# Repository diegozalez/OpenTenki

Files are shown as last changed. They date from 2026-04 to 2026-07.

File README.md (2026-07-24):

# OpenTenki 🚧 Construction in progress 🚧

<table>
  <tr>
    <td valign="middle" width="50%">
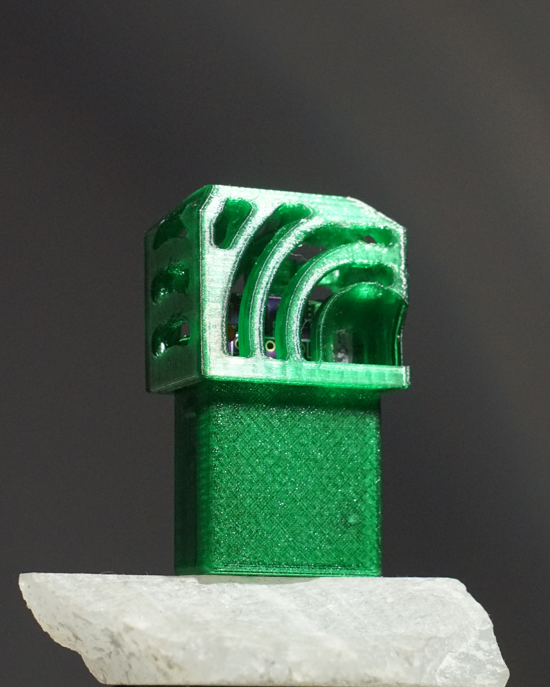
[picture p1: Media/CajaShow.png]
OpenTenki weather station
      
    </td>
    <td valign="middle">
      OpenTenki is an open-source, affordable, and precise indoor weather station
      hardware platform built around an ESP32-S3 mini and multiple environmental
      sensors. It is designed for hobbyists and is compatible with ESPHome and
      Tasmota firmware, enabling easy integration with home automation systems
      via MQTT or Matter.
    </td>
  </tr>
</table>

## Features

<table>
  <tr>
    <td valign="middle">
      <ul>
        <li>Accurate environmental sensing with:
          <ul>
            <li>VEML7700 (ambient light, infrared and full-spectrum light)</li>
            <li>BME688 (temperature, humidity, pressure, air quality)</li>
            <li>HDC3022 (high-precision temperature and humidity)</li>
            <li>WS2812C (NeoPixel) status LED</li>
            <li>User button for control and feedback</li>
          </ul>
        </li>
        <li>Based on the ESP32-S3 mini for robust Wi-Fi and Bluetooth connectivity</li>
        <li>Fully open-source hardware and software</li>
        <li>Designed for easy customization and extension</li>
        <li>Supports MQTT and Matter protocols for data transmission</li>
      </ul>
    </td>
    <td valign="middle" width="50%">
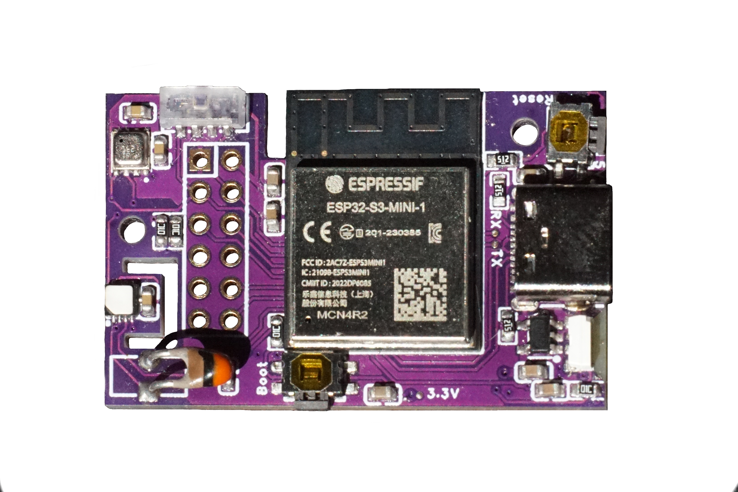
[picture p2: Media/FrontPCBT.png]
OpenTenki PCB render
      
    </td>
  </tr>
</table>

---

## Repository Structure

- [`PCB/`](PCB) — Schematic, Gerber files, BOM, EasyEDA project and PCB renders
- [`Code/`](Code) — Firmware integrations (ESPHome, Tasmota, more coming)
- [`Case3D/`](Case3D) — 3D-printable case files
- [`Media/`](Media) — Photos and renders of the board and case

---

## Getting Started

### Hardware

<table>
  <tr>
    <td valign="middle" width="50%">
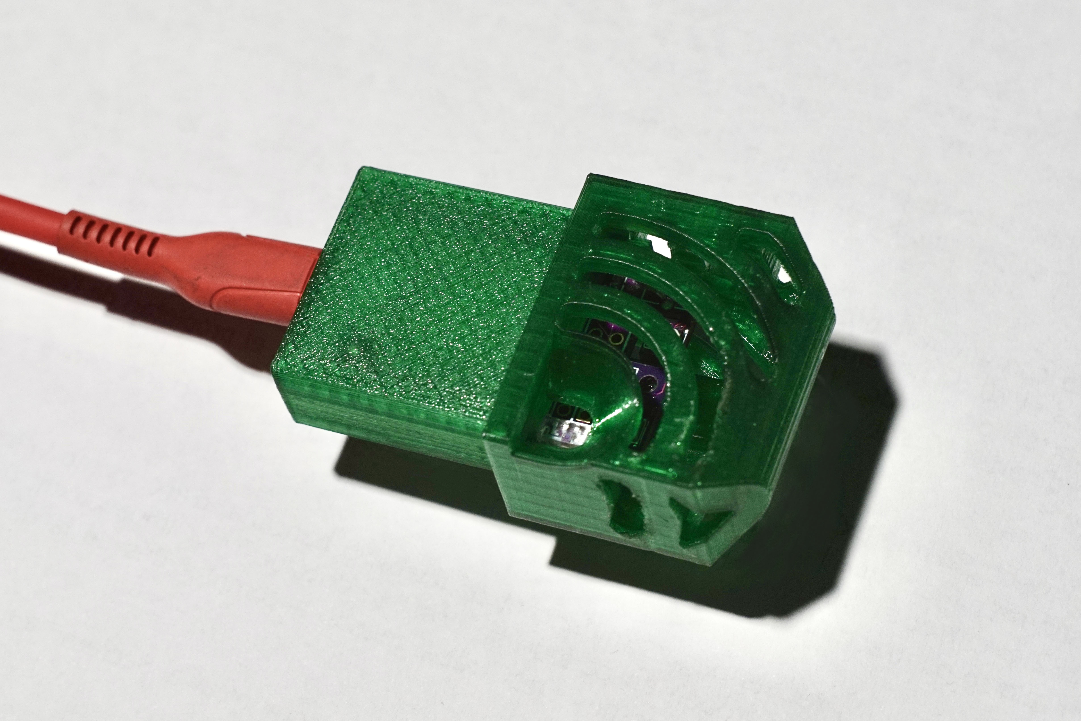
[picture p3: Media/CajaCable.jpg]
OpenTenki assembled, powered over USB-C
      
    </td>
    <td valign="middle">
      <ul>
        <li>Order the PCB with the <a href="PCB/Gerber_PCB2_2026-04-26">Gerber files</a>
          and the <a href="PCB/BOM_OpenTenki_PCB2_2026-07-24.xlsx">BOM</a> — see the
          <a href="PCB">PCB folder</a> for the schematic, the interactive BOM and the
          full EasyEDA project.</li>
        <li>3D-print the <a href="Case3D">case</a>: three printed parts and one screw.</li>
      </ul>
    </td>
  </tr>
</table>

### Firmware

- Compatible with [ESPHome](https://esphome.io/) and
  [Tasmota](https://tasmota.github.io/) out of the box.
- Custom firmware (Arduino, etc.) is in development — contributions welcome!

### Usage

1. Flash ESPHome or Tasmota firmware configured for OpenTenki sensors
   (see [`Code/EspHome/`](Code/EspHome) for a ready-to-use YAML).
2. Connect the board to power and Wi-Fi.
3. Integrate the sensor data with your home automation platform via MQTT or Matter.

---

## Contributing

Contributions, bug reports and feature requests are more than welcome! Please
open an issue or a pull request on GitHub.

---

## License

OpenTenki is licensed under the Apache License 2.0. See [LICENSE](LICENSE) for
details.

---

## Contact

For questions or discussions, open an issue or contact diegozalezz@gmail.com.

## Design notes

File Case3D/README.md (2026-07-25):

# OpenTenki 3D-Printed Case

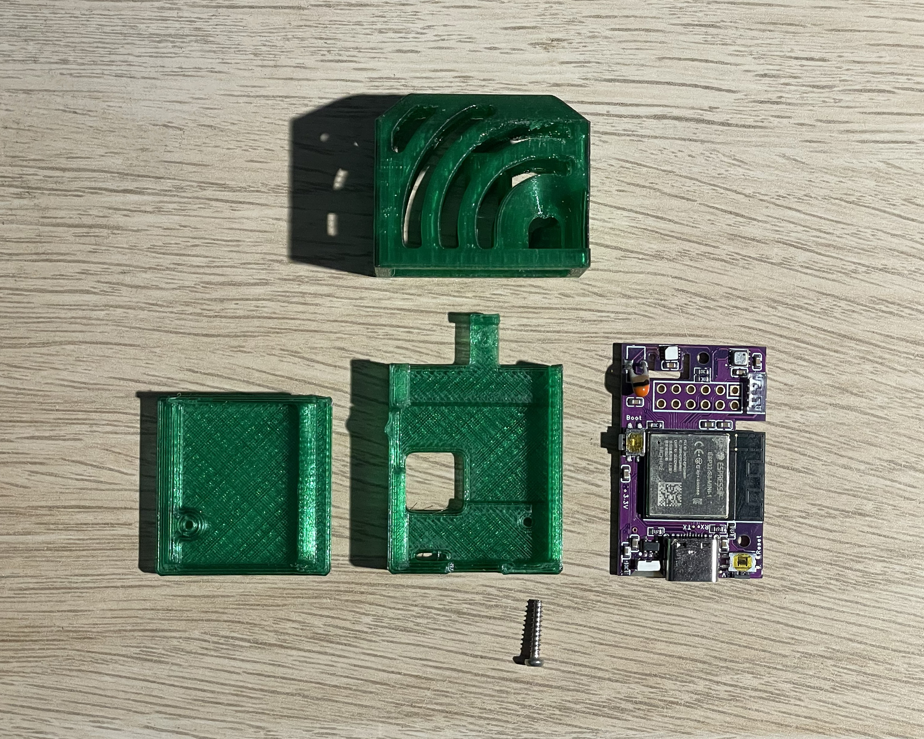
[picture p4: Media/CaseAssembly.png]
The three printed parts, the PCB and the M2×10 screw


The case consists of **three 3D-printed parts** that fit around the PCB and are
secured with a single **M2×10 plastic screw**.

You can also find this model on
[Printables](https://www.printables.com/model/1790374-opentenki-case).

## What you need

- The three `.stl` files in this folder
- An assembled OpenTenki PCB
- 1 × M2×10 plastic screw

## Print & assemble

1. Print the three STL files — standard PLA or PETG settings work fine.
2. Fit the PCB inside the case parts as shown in the picture above.
3. Close the case with the M2×10 screw. Done!

## Modifying the case

The case is designed in [Onshape](https://www.onshape.com/) and the full
assembly is included as a STEP file
([`3D_PCB2_2026-04-23.step`](3D_PCB2_2026-04-23.step)), so you are free to
modify or remix it as you wish.

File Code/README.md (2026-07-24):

# OpenTenki Firmware

Here you can find all the firmware integrations for OpenTenki. In this project
it is very important to be as open and as compatible as possible, so if there
is a platform you would like covered (or that you can adapt OpenTenki to), let
me know — it will only make the project better.

## ESPHome / Home Assistant

The recommended path. The full implementation lives in
[`EspHome/opentenki-v2.yaml`](EspHome/opentenki-v2.yaml) and works great: every
sensor is exposed, the status LED is fully integrated, and pressing the
on-board button confirms connectivity to Home Assistant. The board can also
calculate indoor air quality (IAQ) through the BME688's BSEC2 stack.

## Tasmota

A working [basic template](Tasmota) is available: the BME688, HDC3022, user
button and LED work out of the box (the VEML7700 needs a custom-compiled
binary). Tasmota's ESP32-S3 support is still maturing, so expect some rough
edges — feedback is welcome.

## Arduino — Coming Soon

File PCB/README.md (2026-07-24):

# OpenTenki PCB

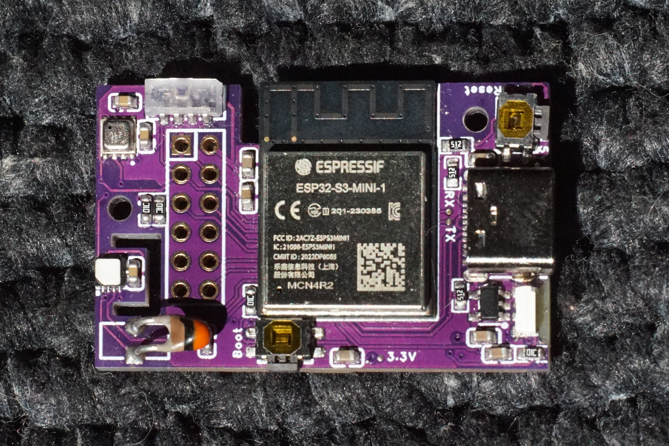
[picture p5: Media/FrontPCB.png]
PCB picture

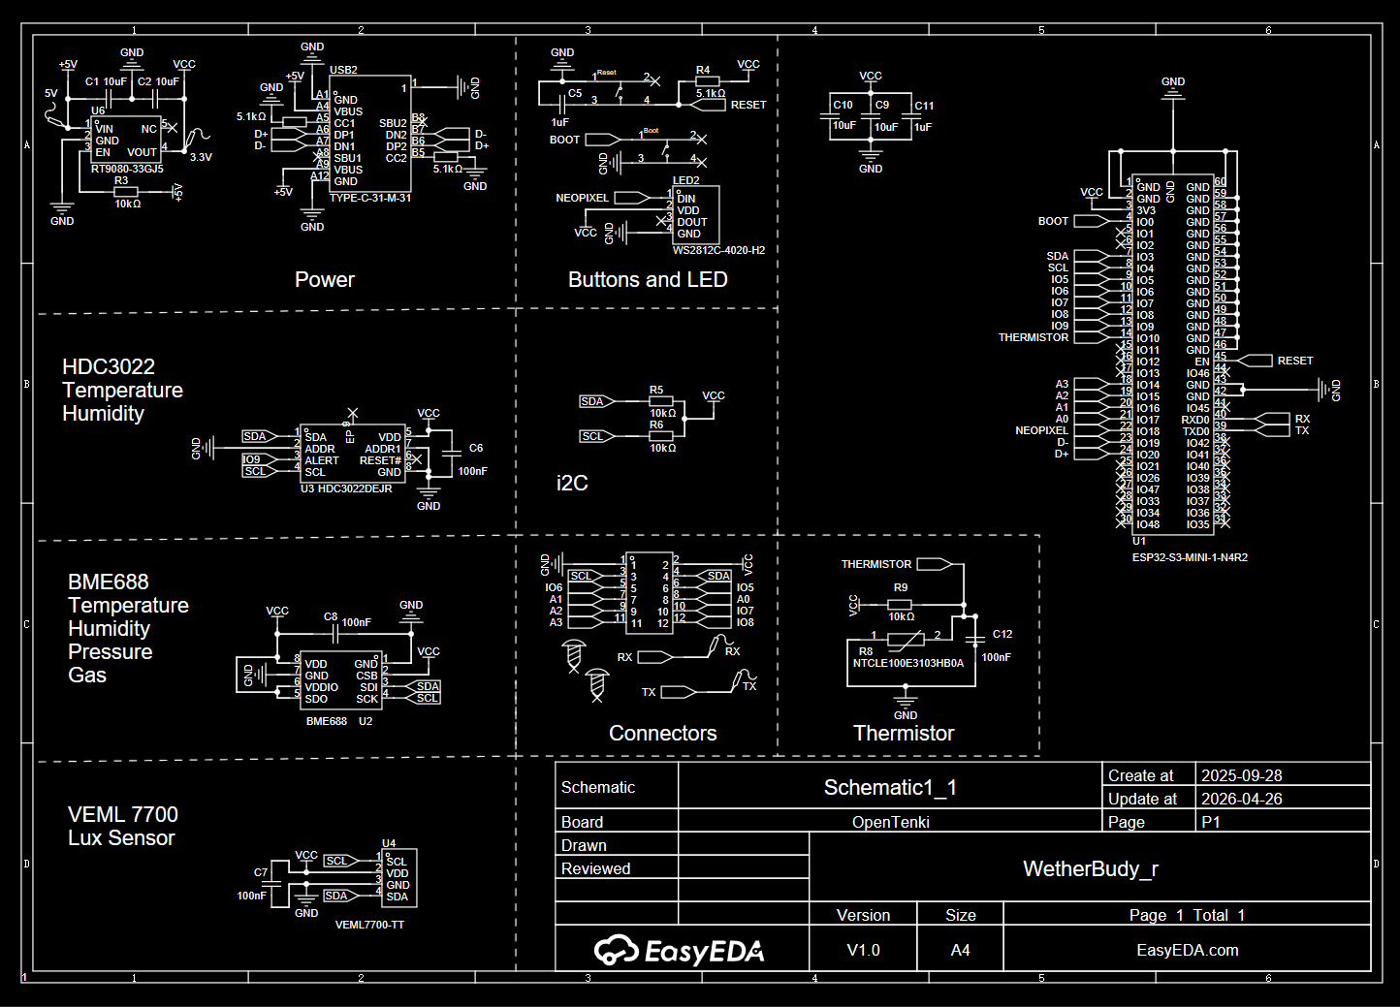
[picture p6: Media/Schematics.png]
Schematic


## Build your own

Everything you need to order and assemble the board:

- [**BOM (Excel)**](BOM_OpenTenki_PCB2_2026-07-24.xlsx) — full part list with LCSC part numbers.
- [**Interactive BOM**](InteractiveBOM_PCB2_2026-4-25.html) — download and open in your browser to locate every component on the board. Very handy for hand soldering.
- [**Gerber files**](Gerber_PCB2_2026-04-26) — ready to send to JLCPCB or any other PCB fab.
- [**Schematic**](SchematicV2.pdf) and [**PCB preview**](PCB_OpenTenki.pdf) as PDF.
- [**EasyEDA project**](OpenTenkiEasyEda.eprj) — the full editable design.

## Components

### Microcontroller

#### ESP32-S3-mini N4R2

This module is great because, in a small form factor, it provides Wi-Fi,
Bluetooth, USB OTG, 4 MB of Quad Flash and 2 MB of Quad PSRAM. It is also
compatible with ESPHome, Tasmota, Arduino, CircuitPython and MicroPython.

### Sensors

All sensors are connected over I²C, with **SDA on GPIO3** and **SCL on GPIO4**.

#### Bosch BME688

Used to monitor air quality, as well as pressure, temperature and humidity.

#### VEML7700

Measures ambient light, infrared and full-spectrum light. A cheap and reliable
option.

#### HDC3022

This last sensor measures temperature and humidity much more precisely than the
BME688 and is significantly cheaper, so if you don't need air quality or
atmospheric pressure it's a great choice. It's also useful any time you want
more precise readings.

## Extras

### WS2812C on GPIO18

Usually known as a NeoPixel, this small status LED can be used for anything,
but its primary use is in ESPHome — the included configuration uses it to show
boot status and to confirm Home Assistant connectivity when the user button is
pressed.

### Button on GPIO0

Doubles as the bootloader button (to flash the board) and as a user button to
check status or to trigger an action on your server.

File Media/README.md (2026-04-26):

# Media for OpenTenki

This folder contains photos and renders of the OpenTenki board and case, used
throughout the rest of the documentation.

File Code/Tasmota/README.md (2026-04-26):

# OpenTenki on Tasmota

With the basic template below you get the BME688, the HDC3022, the user button
and the LED working. The VEML7700 is **not** included by default — to enable it
you need to use a custom-compiled Tasmota binary.

## Basic Template

```json
{"NAME":"OpenTenki","GPIO":[32,1,1,640,608,1,1,1,1,1,1,1,1,1,1,1,1,1,1,1,1,1,1376,0,0,0,0,1,1,1,1,1,1,1,1,1,1,1],"FLAG":0,"BASE":1}
```

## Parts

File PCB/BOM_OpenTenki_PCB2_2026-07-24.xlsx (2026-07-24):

Manufacturer Part | Manufacturer | Value | Supplier | Name | Supplier Part
BME688,CC0603KRX7R9BB104,CL10A105KB8NNNC,CL10A106KP8NNNC,ESP32-S3-MINI-1-N4R2,HDC3022DEJR,NTCLE100E3103HB0A,RC0603FR-075K1L,RC0603FR-0710KL,RT9080-33GJ5,TSD4A 250gf-DZ,TYPE-C-31-M-31,VEML7700-TT,WS2812C-4020-H2,ZX-PZ2.54-2-6PZZ | Bosch(博世),ESPRESSIF(乐鑫),Megastar(兆星),SAMSUNG(三星),SHOU HAN(首韩),TECH PUBLIC(台舟),TI(德州仪器),VISHAY(威世),worldsemi,YAGEO(国巨),韩国韩荣 | 1uF,5.1kΩ,10kΩ,10uF,100nF | LCSC | 1uF,5.1kΩ,10kΩ,10uF,100nF,BME688,ESP32-S3-MINI-1-N4R2,HDC3022DEJR,NTCLE100E3103HB0A,RT9080-33GJ5,TSD4A 250gf-DZ,TYPE-C-31-M-31,VEML7700-TT,WS2812C-4020-H2,ZX-PZ2.54-2-6PZZ | C14663,C15849,C19702,C98220,C105580,C431531,C1850416,C2760486,C3013941,C3153241,C3664478,C7501277,C17434731,C20617299,C42417604

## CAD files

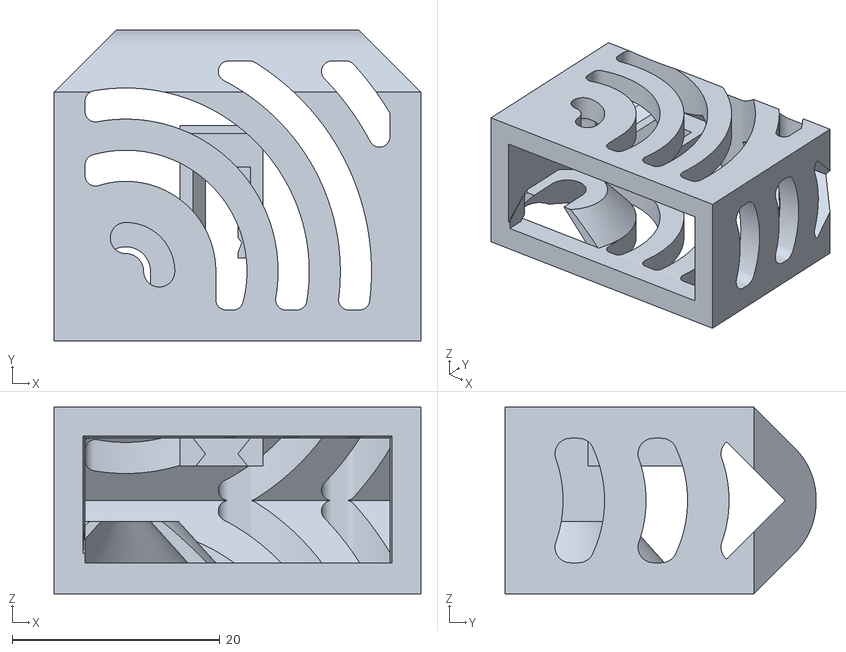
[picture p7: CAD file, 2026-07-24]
Case3D/3D_PCB2_2026-04-23 - Board~3TSI - Part 4.stl
35.4 x 30.0 x 18.0

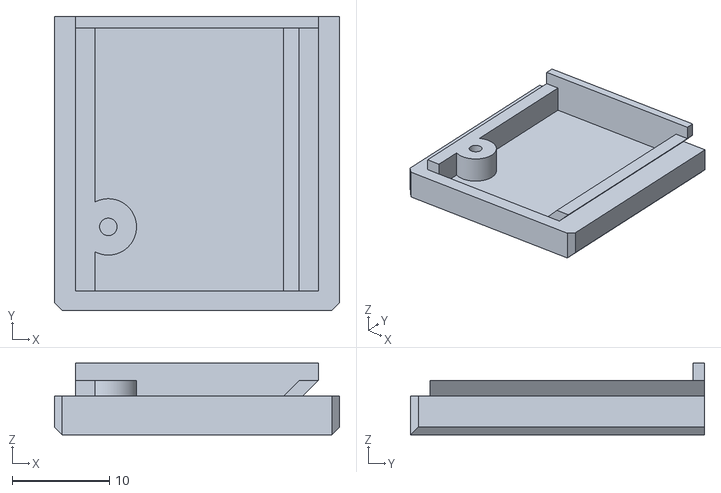
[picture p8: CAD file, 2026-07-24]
Case3D/3D_PCB2_2026-04-23 - Board~3TSI - Part 2.stl
29.4 x 30.3 x 7.40

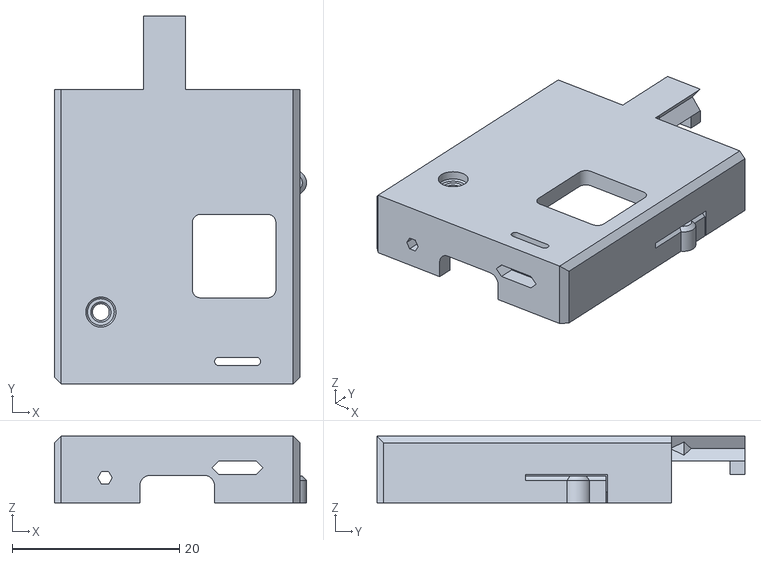
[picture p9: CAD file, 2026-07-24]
Case3D/3D_PCB2_2026-04-23 - Board~3TSI - Part 1.stl
30.2 x 44.0 x 8.00

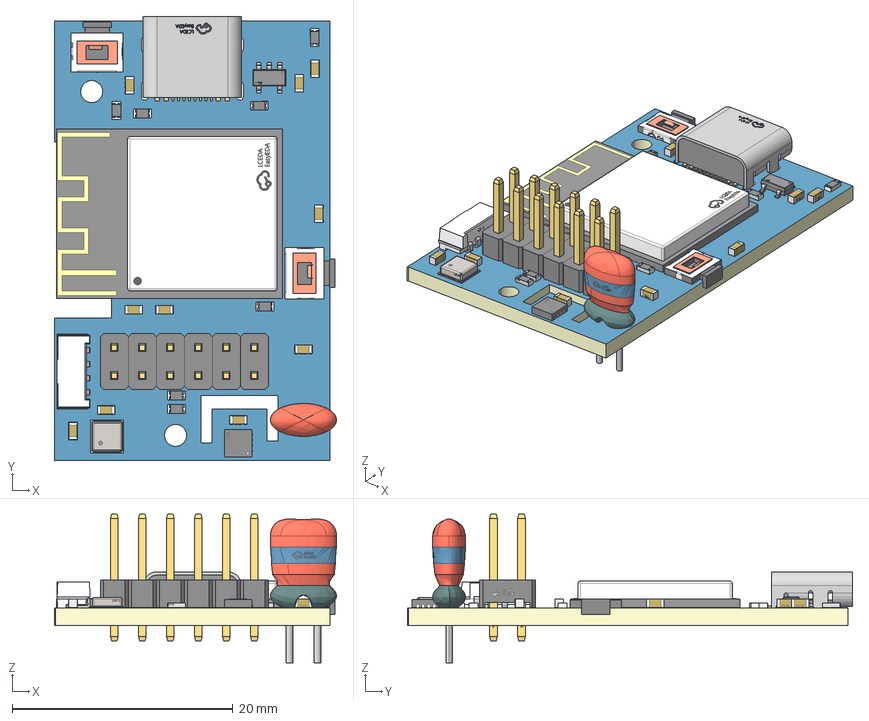
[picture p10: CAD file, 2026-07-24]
Case3D/3D_PCB2_2026-04-23.step
25.6 x 40.4 x 13.5 mm
Board~3TSI
TopCopper~3TSI
BottomCopper~3TSI
TopFpcStiffener~3TSI
BottomFpcStiffener~3TSI
C0603~C0603_L1.6-W0.8-H0.8~3TSI x 10
BULETM-SMD_ESP32-S3-MINI-1-N8~BULETM-SMD_ESP32-S3-MINI-1-N8~3TSI
LGA-8_L3.0-W3.0-P0.80_BME688~LGA-8_L3.0-W3.0-P0.80_BME688~3TSI
SOT-23-5_L3.0-W1.5-P0.95-LS2.8-BL~SOT-23-5_ L3.0-W1.5-P0.95-LS2.8-BL~3TSI
TDFN-8_L2.5-W2.5-P0.50-BL-EP~TDFN-8_L2.5-W2.5-P0.50-BL-EP~3TSI
HDR-TH_12P-P2.54-V-M-R2-C6-S2.54~HDR2.54-M-LI-2X6P~3TSI
USB-C-SMD_TYPE-C-31-M-31~USB-C-SMD_TYPE-C-31-M-31~3TSI
SENSOR-SMD_EML7700-TT~SENSOR-SMD_EML7700-TT~3TSI
SW-SMD_TSD4A~SW-SMD_TSD4A~3TSI x 2
R0603~R0603~3TSI x 7
RES-TH_L6.0-W3.0-P2.54-D0.6~RES-TH_L6.0-W3.0-H8.0-P2.54-D0.6~3TSI

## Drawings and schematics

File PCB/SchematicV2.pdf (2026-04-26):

V1.0 | A4 | EasyEDA.com GND

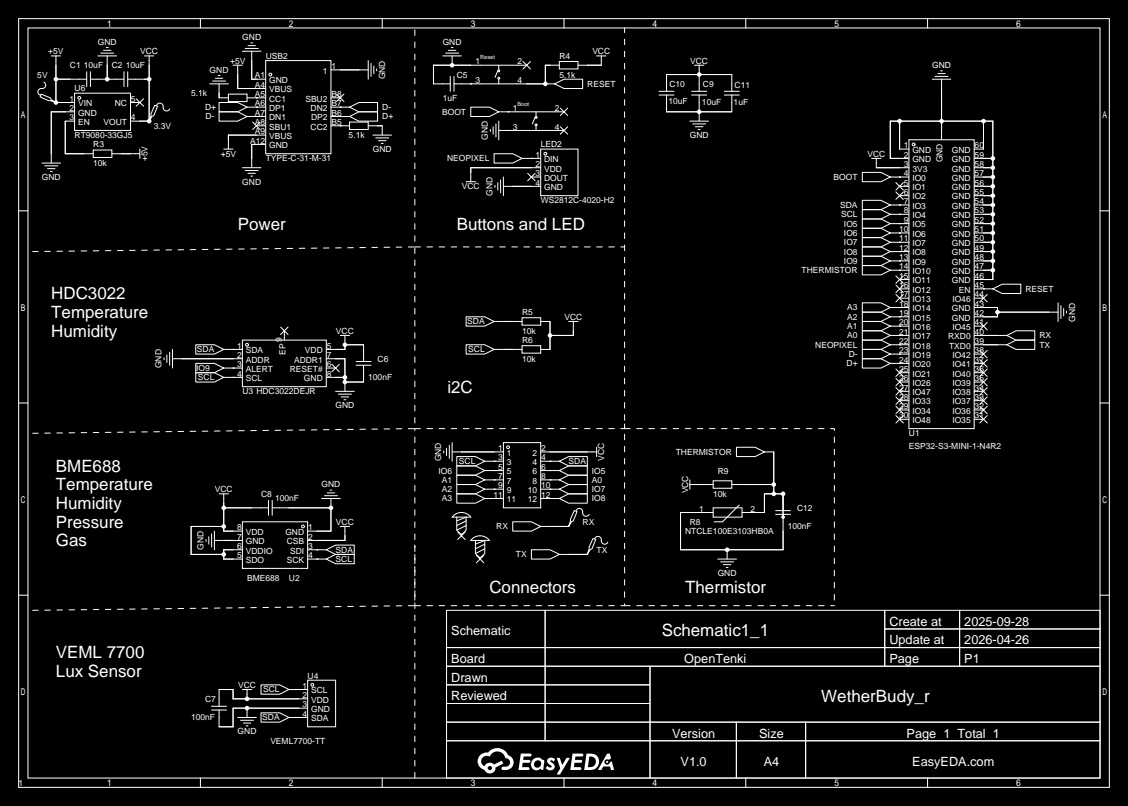
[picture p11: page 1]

Schematic | Schematic1_1 | Create at | 2025-09-28

Update at | 2026-04-26

Board | OpenTenki | Page | P1
Drawn | | WetherBudy_r
Reviewed

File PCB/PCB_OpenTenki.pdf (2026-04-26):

RX

5V

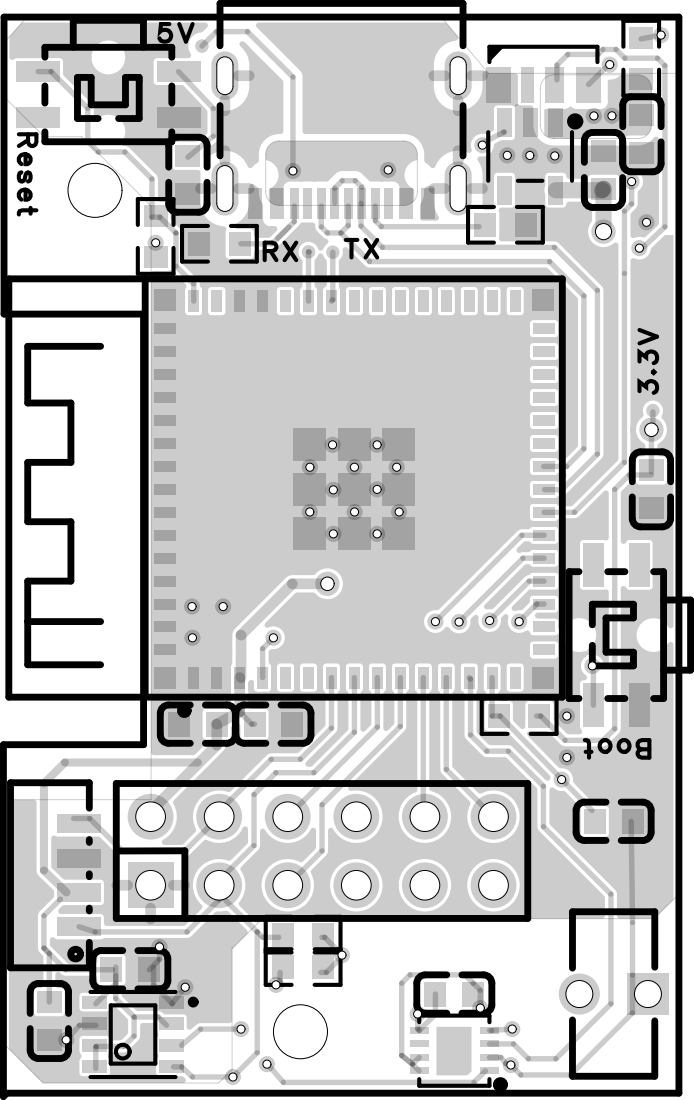
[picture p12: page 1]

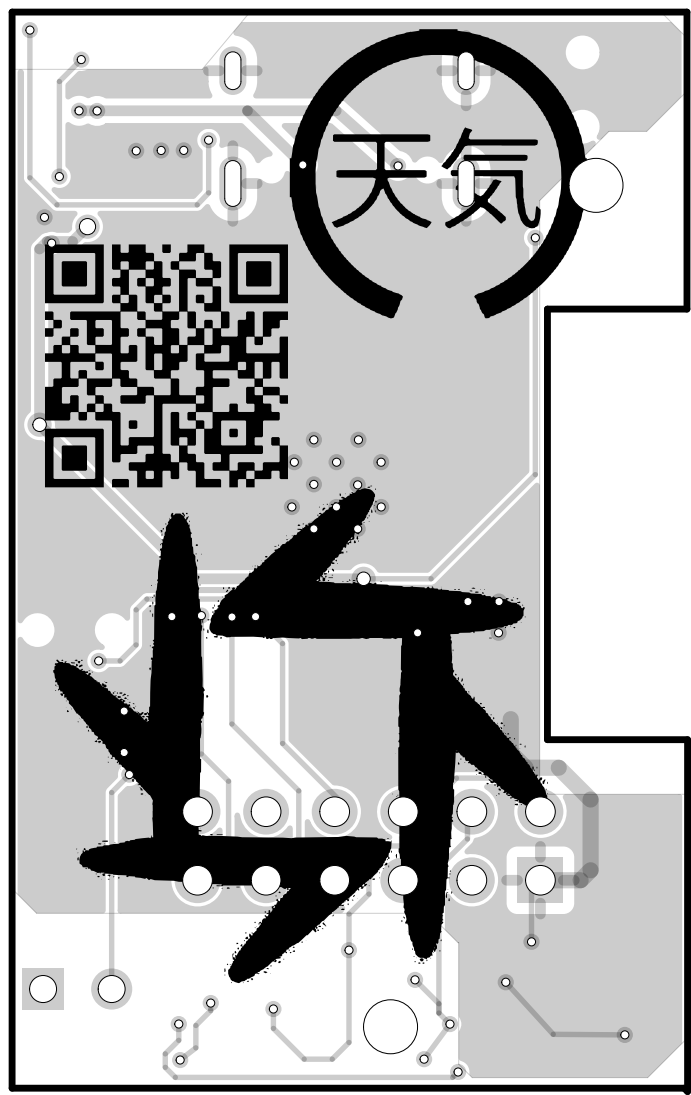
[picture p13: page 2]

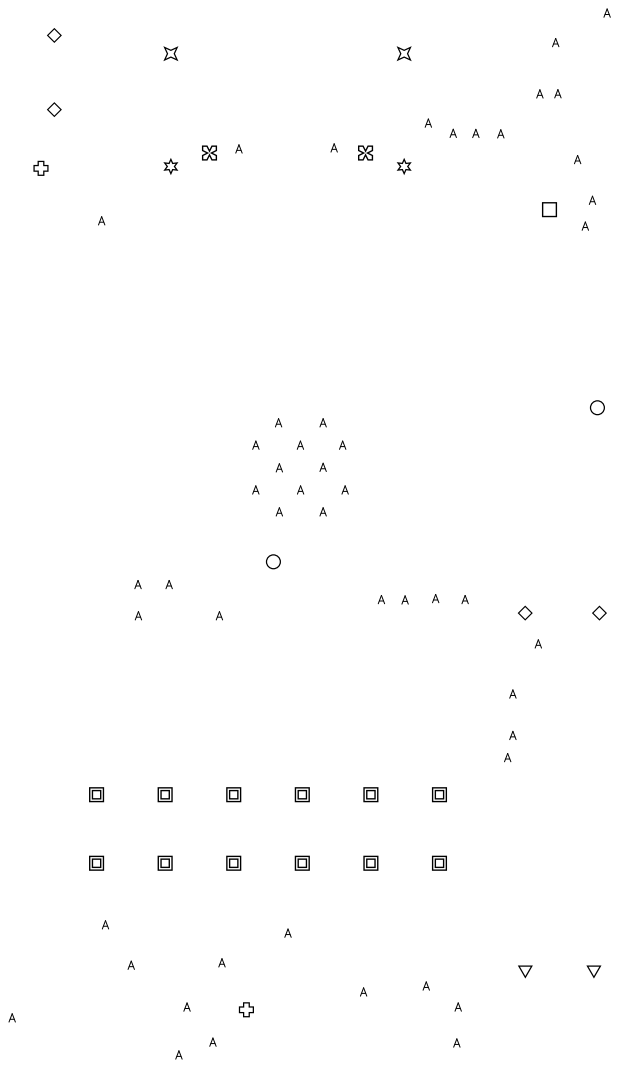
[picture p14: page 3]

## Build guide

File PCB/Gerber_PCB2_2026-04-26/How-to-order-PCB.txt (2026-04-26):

How to Order PCB

Please refer to:
https://prodocs.easyeda.com/en/pcb/order-order-pcb/index.html

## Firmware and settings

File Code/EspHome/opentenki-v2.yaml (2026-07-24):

esphome:
  name: opentenki-v2
  friendly_name: OpenTenki_v2
  on_boot:
    - priority: 600
      then:
        - logger.log: "First Boot"
        - script.execute: led_blue_blink
        - delay: 20s
        - script.execute: led_status_script
 
 
esp32:
  board: adafruit_feather_esp32s3
  framework:
    type: esp-idf
  cpu_frequency: 80MHz
 
 
# Enable logging
logger:
 
 
# Enable Home Assistant API
api:
  encryption:
    key: "iHoU0qKRK1Fompx4+k6X/awJ/K7FVuPgAIsV7tkNat4="
 
ota:
  - platform: esphome
    password: "aac6b9fbe54c93224300b730235b287a"
 
wifi:
  ssid: !secret wifi_ssid
  password: !secret wifi_password
  power_save_mode: HIGH
 
  # Enable fallback hotspot (captive portal) in case wifi connection fails
  ap:
    ssid: "Opentenki"
    password: "opentenkiCA"
 
captive_portal:
 
 
external_components:
  - source: github://HarpalPannu/hdc302x-esphome
    components: [hdc302x]
 
# --- I2C bus (SDA=3, SCL=4) ---
i2c:
  sda: 3
  scl: 4
  scan: true
 
 
bme68x_bsec2_i2c:
  id: bme68x_ai
  address: 0x77
  model: bme688
  operating_age: 28d
  sample_rate: ULP             # ULP = every ~5 min, reduces self-heating significantly
  supply_voltage: 3.3V
  state_save_interval: 6h
 
 
# ============================================
# Sensors: BME688, VEML7700, HDC3022, Thermistor
# "Temperature" (HDC3022) is the primary temperature entity;
# other temperature readings are diagnostic.
# ============================================
 
sensor:
  # --- BME688 via BSEC2 (timing controlled by sample_rate: ULP above) ---
  - platform: bme68x_bsec2
    bme68x_bsec2_id: bme68x_ai
    temperature:
      name: "BME688 Temperature"
      entity_category: "diagnostic"
    pressure:
      name: "Pressure"
    humidity:
      name: "BME688 Humidity"
    gas_resistance:
      name: "Gas Resistance"
      unit_of_measurement: "Ω"
    iaq:
      name: "IAQ"
      id: bme688_iaq
    co2_equivalent:
      name: "CO2 Equivalent"
    breath_voc_equivalent:
      name: "Breath VOC Equivalent"
 
  # --- VEML7700 Lux sensor ---
  - platform: veml7700
    address: 0x10
    update_interval: 300s      # 5 min
    ambient_light: "Ambient Light"
    full_spectrum: "Full Spectrum"
    infrared: "Infrared"
 
  # --- HDC3022 Temperature & Humidity ---
  # Temperature (with -5.0 offset) is the primary temperature entity
  - platform: hdc302x
    update_interval: 300s      # 5 min
    address: 0x44
    temperature:
      name: "Temperature"
      id: hdc302x_temperature
      filters:
        - offset: -5.0         # manual correction offset
    humidity:
      name: "Humidity"
      id: hdc302x_humidity
 
  # --- WiFi signal ---
  - platform: wifi_signal
    name: "WiFi Signal dB"
    id: wifi_signal_db
    update_interval: 300s      # 5 min
    entity_category: "diagnostic"
 
  # --- ESP32 internal die temperature ---
  - platform: internal_temperature
    name: "Internal Temperature"
    id: internal_temp
    update_interval: 300s      # 5 min
    entity_category: "diagnostic"
 
  # ============================================
  # NTCLE100E3103HB0A Thermistor on GPIO10
  # Voltage divider: 3.3V → 10kΩ → GPIO10 → Thermistor → GND
  # ============================================
  - platform: adc
    pin: GPIO10
    id: thermistor_voltage
    name: "Thermistor Raw Voltage"
    attenuation: 12db          # Full 0–3.3V range on ESP32-S3
    update_interval: 300s      # 5 min
    internal: true
 
  - platform: resistance
    id: thermistor_resistance
    sensor: thermistor_voltage
    configuration: DOWNSTREAM  # Thermistor is between pin and GND
    resistor: 10kΩ
    internal: true
 
  - platform: ntc
    sensor: thermistor_resistance
    name: "Thermistor Temperature"
    unit_of_measurement: "°C"
    accuracy_decimals: 1
    icon: "mdi:thermometer"
    entity_category: "diagnostic"
    calibration:
      # Steinhart-Hart B-parameter for NTCLE100E3103HB0A (Vishay datasheet)
      b_constant: 3977
      reference_temperature: 25°C
      reference_resistance: 10kΩ
 
 
# --- IAQ accuracy text sensor ---
text_sensor:
  - platform: bme68x_bsec2
    bme68x_bsec2_id: bme68x_ai
    iaq_accuracy:
      name: "IAQ Accuracy"
 
 
# ===========================
# WS2812C RGB Status LED
# ===========================
 
light:
  - platform: esp32_rmt_led_strip
    rgb_order: GRB
    pin: GPIO18
    num_leds: 1
    chipset: ws2812
    name: "Status LED"
    id: status_led
 
 
# ----------------------
# Binary sensors
# ----------------------
binary_sensor:
 
  - platform: status
    name: "ESP32 Status"
    id: device_status
 
  - platform: gpio
    pin:
      number: 0
      mode: INPUT_PULLUP
      inverted: True
    name: "Button GPIO0"
    on_press:
      then:
        - script.execute: led_status_script
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

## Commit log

2026-04-26 Error correction
    [Drill_NPTH_Through.DRL, Drill_PTH_Through.DRL, Drill_PTH_Through_Via.DRL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]
2026-07-24 Add 3D case files, BOM and improve documentation
    - Case3D: add the three STL parts + STEP assembly, rewrite README as a simple print guide
    - PCB: add BOM (xlsx) and interactive BOM (html), add 'Build your own' section
    - Media: fix filenames (Schematics.png, CaseAssembly.png)
    - Code: update Tasmota section (template available, still polishing)
    - Main README: new intro layout with CajaCable photo, GitHub-safe formatting, BOM/case links
    [3D_PCB2_2026-04-23 - Board~3TSI - Part 1.stl, 3D_PCB2_2026-04-23 - Board~3TSI - Part 2.stl, 3D_PCB2_2026-04-23 - Board~3TSI - Part 4.stl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]
2026-07-24 README: swap Features/Hardware images (PCB render in Features)
2026-07-25 Case3D: add Printables link
